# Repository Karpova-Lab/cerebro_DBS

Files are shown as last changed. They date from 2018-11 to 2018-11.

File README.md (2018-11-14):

# CerebroDBS Wireless Deep Brain Stimulation System

This repository contains all files needed to replicate a wireless DBS system that was developed in the [Karpova Lab ](https://www.janelia.org/lab/karpova-lab) at HHMI's Janelia Research Campus.

## Licenses
The MIT License (MIT)

Copyright (c) 2018 Andy Lustig

Permission is hereby granted, free of charge, to any person obtaining a copy of this software and associated documentation files (the “Software”), to deal in the Software without restriction, including without limitation the rights to use, copy, modify, merge, publish, distribute, sublicense, and/or sell copies of the Software, and to permit persons to whom the Software is furnished to do so, subject to the following conditions:

The above copyright notice and this permission notice shall be included in all copies or substantial portions of the Software.

THE SOFTWARE IS PROVIDED “AS IS”, WITHOUT WARRANTY OF ANY KIND, EXPRESS OR IMPLIED, INCLUDING BUT NOT LIMITED TO THE WARRANTIES OF MERCHANTABILITY, FITNESS FOR A PARTICULAR PURPOSE AND NONINFRINGEMENT. IN NO EVENT SHALL THE AUTHORS OR COPYRIGHT HOLDERS BE LIABLE FOR ANY CLAIM, DAMAGES OR OTHER LIABILITY, WHETHER IN AN ACTION OF CONTRACT, TORT OR OTHERWISE, ARISING FROM, OUT OF OR IN CONNECTION WITH THE SOFTWARE OR THE USE OR OTHER DEALINGS IN THE SOFTWARE.

<a rel="license" href="http://creativecommons.org/licenses/by-sa/4.0/">
      </a>
      <br /><span xmlns:dct="http://purl.org/dc/terms/" property="dct:title">Cerebro Wireless Optogenetics System</span> by
      <a xmlns:cc="http://creativecommons.org/ns#" href="https://www.janelia.org/lab/karpova-lab" property="cc:attributionName" rel="cc:attributionURL">
      Andy Lustig </a> is licensed under a  <a rel="license" href="http://creativecommons.org/licenses/by-sa/4.0/">Creative Commons Attribution-ShareAlike 4.0 International License</a>

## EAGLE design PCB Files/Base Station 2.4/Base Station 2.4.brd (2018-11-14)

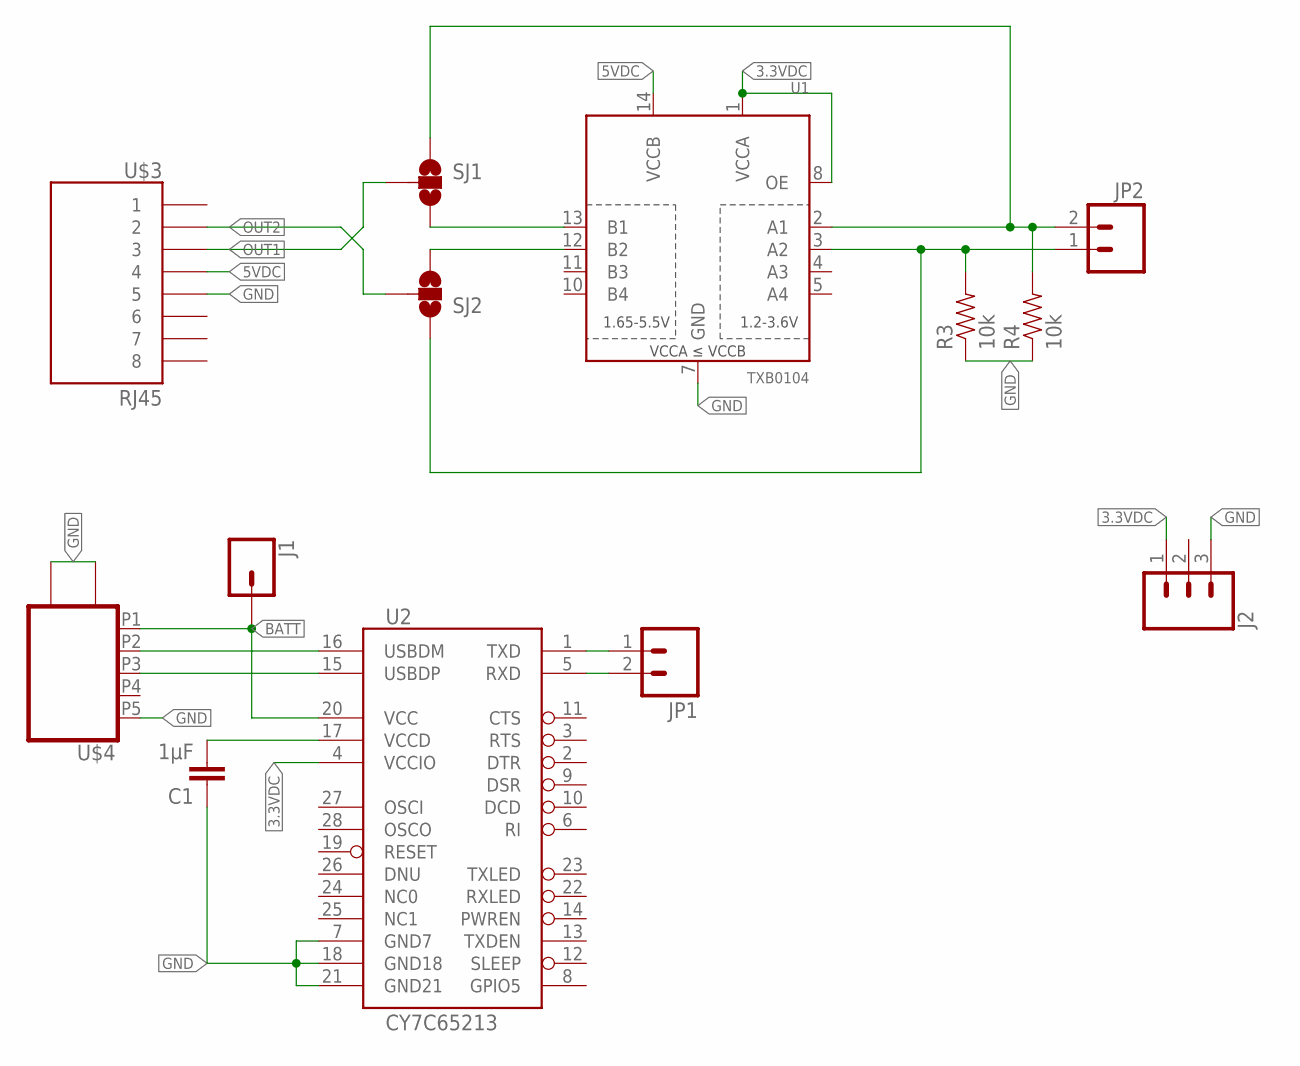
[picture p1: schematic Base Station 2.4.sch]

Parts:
C1: 1µF; 0603
J1: CONN_01PTH_NO_SILK_YES_STOP; 1X01_NO_SILK
J2: CONN_031X03_NO_SILK; 1X03_NO_SILK
JP1, JP2: M021X02_NO_SILK; 1X02_NO_SILK
R3, R4: 10k; 0805
SJ1, SJ2: SOLDERJUMPER_2WAYPASTE2&3; SJ_3_PASTE2&3
U1: TXB0104; TSSOP14
U2: CY7C65213; SSOP28DB
U$3: RJ45; RJ45-8
U$4: USB_MICRO_SOCKET_HORZ_REINFORCED; USB_HORZ_REINFORCED_MICRO

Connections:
3.3VDC: J2.1, U1.1 (VCCA), U1.8 (OE), U2.4 (VCCIO)
5VDC: U1.14 (VCCB), U$3.4
BATT: J1.1, U2.20 (VCC), U$4.P1
GND: C1.1, J2.3, R3.1, R4.1, U1.7 (GND), U2.7 (GND7), U2.18 (GND18), U2.21 (GND21), U$3.5, U$4.G1, U$4.G2, U$4.P5, U$4.P$1, U$4.P$2
unnamed: JP1.1, U2.1 (TXD)
unnamed: JP1.2, U2.5 (RXD)
unnamed: U2.15 (USBDP), U$4.P3
unnamed: U2.16 (USBDM), U$4.P2
unnamed: C1.2, U2.17 (VCCD)
unnamed: JP2.2, R4.2, SJ1.1, U1.2 (A1)
unnamed: JP2.1, R3.2, SJ2.1, U1.3 (A2)
unnamed: SJ2.3, U1.12 (B2)
unnamed: SJ1.3, U1.13 (B1)
NC1: U2.25 (NC1)
OUT1: SJ1.2, U$3.3
OUT2: SJ2.2, U$3.2

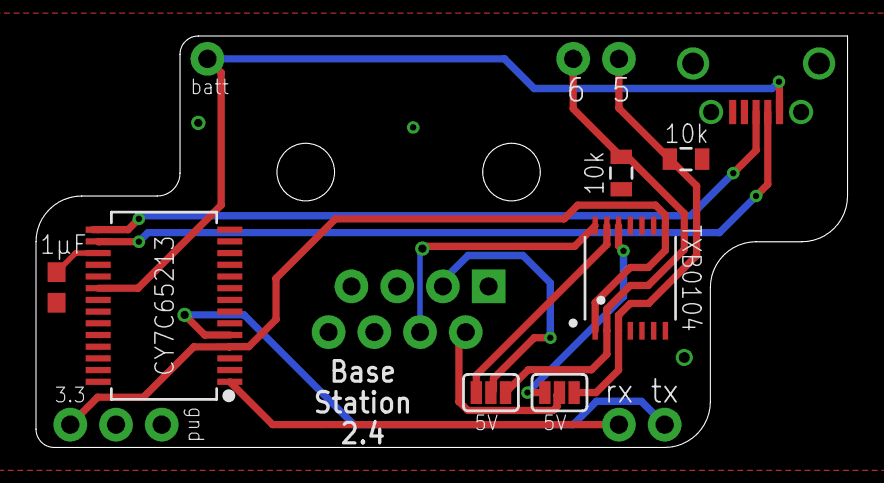
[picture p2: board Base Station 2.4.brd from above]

Board: 2 copper layers, 45.1 x 22.9 mm, 13 parts (0 on the bottom side), 15 nets.

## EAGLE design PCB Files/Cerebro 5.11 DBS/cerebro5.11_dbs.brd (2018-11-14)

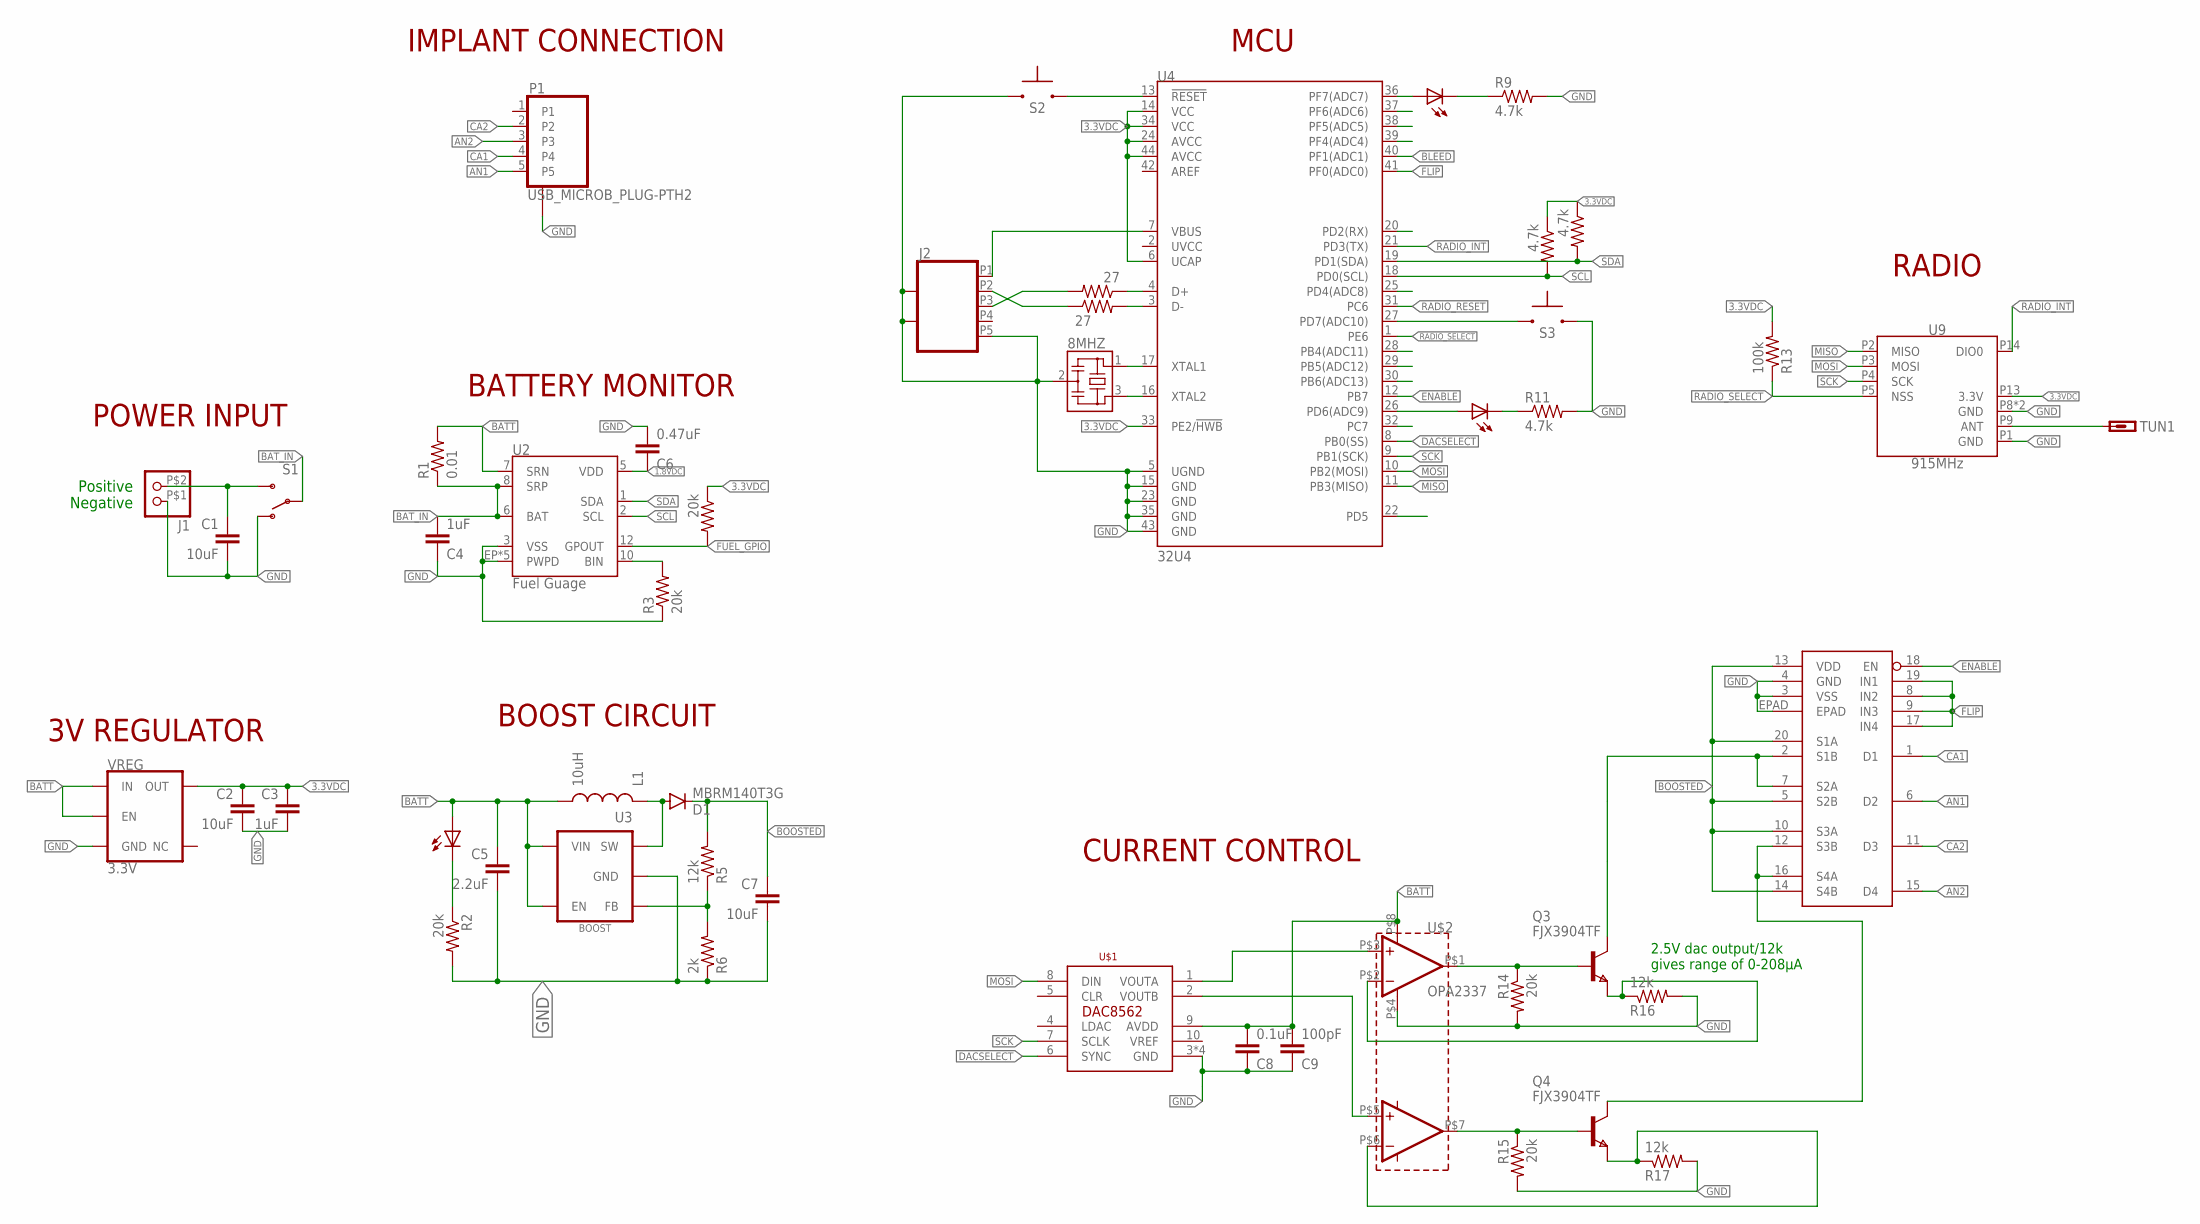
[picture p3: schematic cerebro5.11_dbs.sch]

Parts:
8MHZ: RESONATOR_CSTCE_V; CSTCE_V
C1, C2, C7: 10uF; 0805
C3, C4: 1uF; 0805
C5: 2.2uF; 0805
C6: 0.47uF; 0805
C8: 0.1uF; 0805
C9: 100pF; 0805
D1: MBRM140T3G; POWERMITE
J1: JST_2PINMICRO; MICRO_LOCK_2PIN
J2: USB_MICRO_SOCKET_HORZ_REINFORCED; USB_HORZ_REINFORCED_MICRO
L1: 10uH; 1812
LED1: RED; CHIP-LED0603
LED2, LED3: YLW; CHIP-LED0603
P1: USB_MICROB_PLUG-PTH2; MICRO-B-TH
Q3, Q4: FJX3904TF; SOT323
R1: 0.01; 1206
R2, R3, R4, R14, R15: 20k; 0603-RES
R5: 12k; 0805
R6: 2k; 0603-RES
R7, R8: 27; 0603-RES
R9, R10, R11, R12: 4.7k; 0603-RES
R13: 100k; 0603-RES
R16, R17: 12k; 0603-RES
S1: SWITCH-SPDTREINFORCED_SMD; SWITCH-SPDT-SMD-REINFORCED
S2, S3: SWITCH-MOMENTARY-NO; SWITCH_MOMENTARY_XS
TUN1: ANTENNA; 1X01
U2: Fuel Guage; PDSO-N12
U3: BOOST; SOT23-5
U4: 32U4; QFN-44-NOPAD
U9: 915MHz; RFM69HCW-XXXS2
U$1: DAC8562; WSON-10
U$2: OPA2337; SOT23-8
U$3: ADG1434; LFCSP_5X5
VREG: 3.3V; SOT23-5

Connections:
1.8VDC: C6.1, U2.5 (VDD)
3.3VDC: C2.1, C3.1, R4.1, R10.1, R12.1, R13.2, U4.6 (UCAP), U4.14 (VCC), U4.24 (AVCC), U4.33 (PE2/!HWB), U4.34 (VCC), U4.44 (AVCC), U9.P13 (3.3V), VREG.5 (OUT)
AN1: P1.5, U$3.6 (D2)
AN2: P1.3, U$3.15 (D4)
BATT: C5.1, C8.2, C9.2, L1.P$2 (2), L1.P$4 (2), LED1.A, R1.2, U2.7 (SRN), U3.4 (EN), U3.5 (VIN), U$1.9 (AVDD), U$2.P$8 (V+), VREG.1 (IN), VREG.3 (EN)
BAT_IN: C4.2, R1.1, S1.2, U2.6 (BAT), U2.8 (SRP)
BLEED: U4.40 (PF1(ADC1))
BOOSTED: C7.1, D1.CATHODE (C), R5.2, U$3.5 (S2B), U$3.10 (S3A), U$3.13 (VDD), U$3.14 (S4B), U$3.20 (S1A)
CA1: P1.4, U$3.1 (D1)
CA2: P1.2, U$3.11 (D3)
DACSELECT: U4.8 (PB0(SS)), U$1.6 (SYNC)
ENABLE: U4.12 (PB7), U$3.18 (EN)
FLIP: U4.41 (PF0(ADC0)), U$3.8 (IN2), U$3.9 (IN3), U$3.17 (IN4), U$3.19 (IN1)
FUEL_GPIO: R4.2, U2.12 (GPOUT)
GND: 8MHZ.2, C1.2, C2.2, C3.2, C4.1, C5.2, C6.2, C7.2, C8.1, C9.1, J1.P$1 (1), J2.G1, J2.G2, J2.P5, J2.P$1, J2.P$2, P1.P$1 (GND_PINS), P1.P$2 (GND_PINS), R2.2, R3.1, R6.1, R9.2, R11.2, R14.2, R15.2, R16.2, R17.2, S1.1 (O), S2.P$1 (1), S3.P$2 (2), U2.3 (VSS), U2.EP (PWPD), U2.EP1 (PWPD), U2.EP2 (PWPD), U2.EP3 (PWPD), U2.EP4 (PWPD), U3.2 (GND), U4.5 (UGND), U4.15 (GND), U4.23 (GND), U4.35 (GND), U4.43 (GND), U9.P1 (GND), U9.P8 (GND), U9.P10 (GND), U$1.3 (GND), U$1.G1 (GND), U$1.G2 (GND), U$1.G3 (GND), U$2.P$4 (V-), U$3.3 (VSS), U$3.4 (GND), U$3.EPAD, VREG.2 (GND)
MISO: U4.11 (PB3(MISO)), U9.P2 (MISO)
MOSI: U4.10 (PB2(MOSI)), U9.P3 (MOSI), U$1.8 (DIN)
unnamed: Q3.2 (B), R14.1, U$2.P$1 (OUTA)
unnamed: Q4.2 (B), R15.1, U$2.P$7 (OUTB)
unnamed: Q4.3 (E), R17.1, U$2.P$6 (INB-)
unnamed: C1.1, J1.P$2 (2), S1.3 (S)
unnamed: Q3.3 (E), R16.1, U$2.P$2 (INA-)
unnamed: LED1.C, R2.1
unnamed: R5.1, R6.2, U3.3 (FB)
unnamed: 8MHZ.1, U4.17 (XTAL1)
unnamed: 8MHZ.3, U4.16 (XTAL2)
unnamed: J2.P1, U4.7 (VBUS)
unnamed: D1.ANODE (A), L1.P$1 (1), L1.P$3 (1), U3.1 (SW)
unnamed: R7.1, U4.4 (D+)
unnamed: R8.2, U4.3 (D-)
unnamed: J2.P3, R7.2
unnamed: J2.P2, R8.1
unnamed: LED3.C, R11.1
unnamed: S3.P$1 (1), U4.27 (PD7(ADC10))
unnamed: TUN1.1, U9.P9 (ANT)
unnamed: LED2.C, R9.1
unnamed: LED2.A, U4.36 (PF7(ADC7))
unnamed: R3.2, U2.10 (BIN)
unnamed: Q4.1 (C), U$3.12 (S3B), U$3.16 (S4A)
unnamed: LED3.A, U4.26 (PD6(ADC9))
unnamed: U$1.1 (VOUTA), U$2.P$3 (INA+)
unnamed: U$1.2 (VOUTB), U$2.P$5 (INB+)
unnamed: Q3.1 (C), U$3.2 (S1B), U$3.7 (S2A)
RADIO_INT: U4.21 (PD3(TX)), U9.P14 (DIO0)
RADIO_RESET: U4.31 (PC6)
RADIO_SELECT: R13.1, U4.1 (PE6), U9.P5 (NSS)
RESET: S2.P$2 (2), U4.13 (!RESET)
SCK: U4.9 (PB1(SCK)), U9.P4 (SCK), U$1.7 (SCLK)
SCL: R10.2, U2.2 (SCL), U4.18 (PD0(SCL))
SDA: R12.2, U2.1 (SDA), U4.19 (PD1(SDA))

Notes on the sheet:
Positive
Negative
BOOST CIRCUIT
CURRENT CONTROL
RADIO
3V REGULATOR
BATTERY MONITOR
POWER INPUT
IMPLANT CONNECTION
MCU
2.5V dac output/12k gives range of 0-208µA

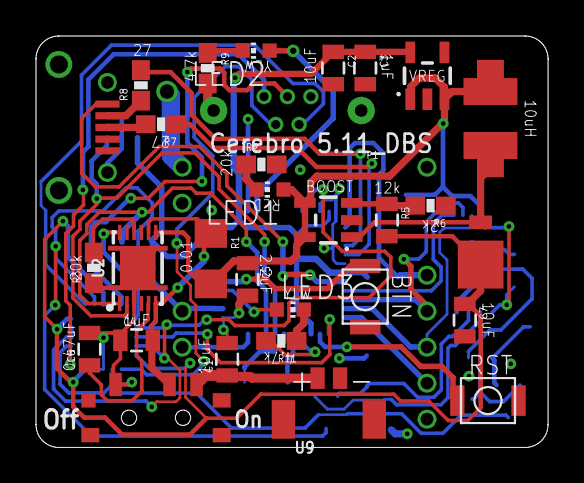
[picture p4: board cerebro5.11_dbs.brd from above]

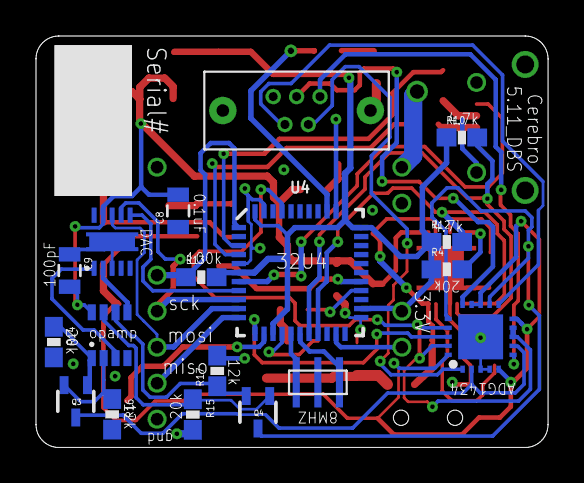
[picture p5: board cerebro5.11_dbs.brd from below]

Board: 2 copper layers, 28.4 x 22.9 mm, 49 parts (18 on the bottom side), 48 nets.

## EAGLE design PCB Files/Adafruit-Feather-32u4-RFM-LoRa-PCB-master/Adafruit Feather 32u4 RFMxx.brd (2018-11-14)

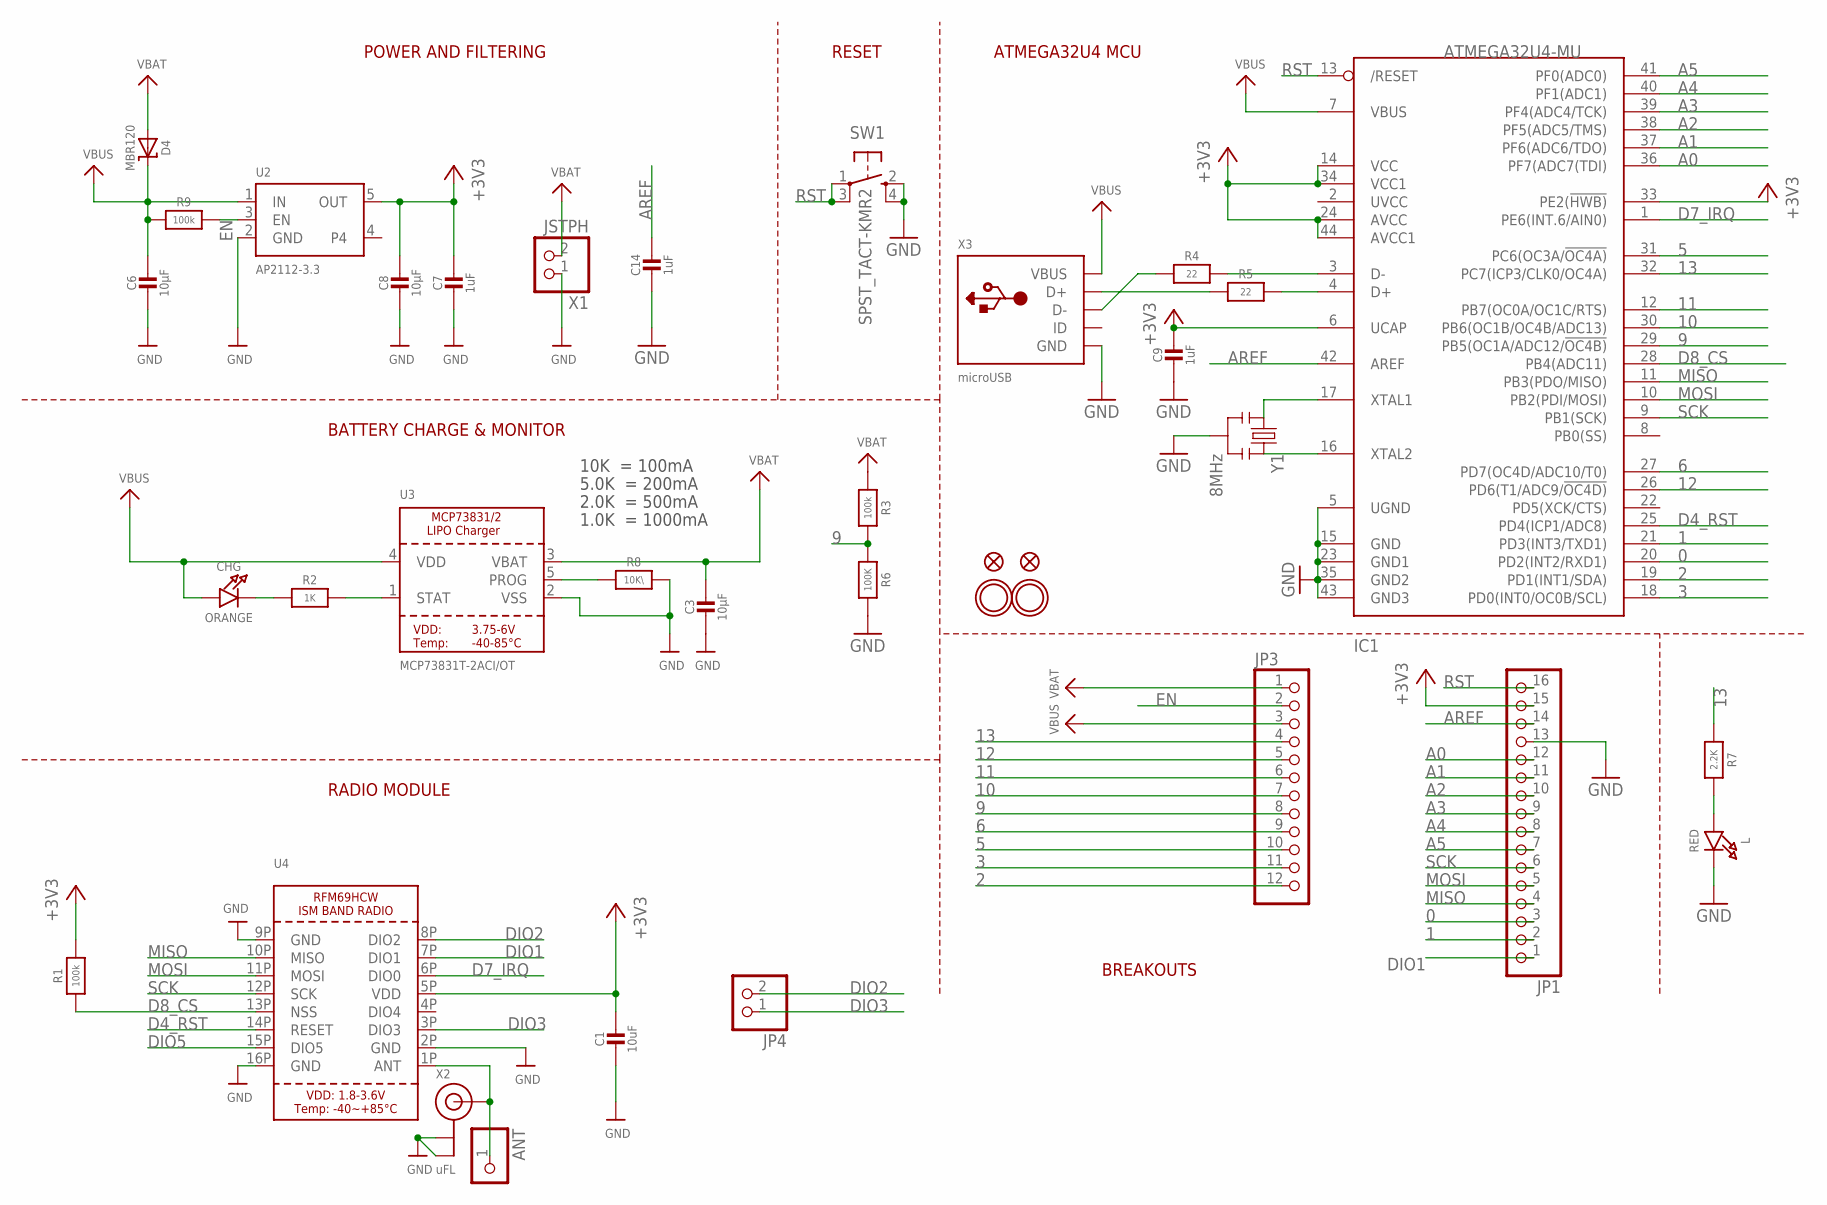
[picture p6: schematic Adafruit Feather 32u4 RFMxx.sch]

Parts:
ANT: HEADER-1X1ROUND; 1X01_ROUND
C1: 10uF; 0805-NO
C3, C6, C8: 10µF; 0805-NO
C7, C14: 1uF; 0603-NO
C9: 1uF; _0603MP
CHG: ORANGE; CHIPLED_0805_NOOUTLINE
D4: MBR120; SOD-123
IC1: ATMEGA32U4-MU; TQFN44_7MM
JP1: HEADER-1X16ROUND; 1X16_ROUND
JP3: HEADER-1X12; 1X12_ROUND
JP4: HEADER-1X2ROUND; 1X02_ROUND
L: RED; CHIPLED_0805_NOOUTLINE
R1, R3, R9: 100k; 0603-NO
R2: 1K; 0603-NO
R4, R5: 22; 0603-NO
R6: 100K; 0603-NO
R7: 2.2K; 0603-NO
R8: 10K\; 0603-NO
SW1: SPST_TACT-KMR2; KMR2
U2: AP2112-3.3; SOT23-5
U3: MCP73831T-2ACI/OT; SOT23-5
U4: RFM69HCW_SMT; RFMHCW_SMT
U$31, U$32: MOUNTINGHOLE2.5; MOUNTINGHOLE_2.5_PLATED
U$34, U$35: FIDUCIAL""; FIDUCIAL_1MM
X1: JSTPH; JSTPH2
X2: uFL; U.FL
X3: microUSB; 4UCONN_20329_V2
Y1: 8MHz; RESONATOR-SMD

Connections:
0: IC1.20 (PD2(INT2/RXD1)), JP1.3
1: IC1.21 (PD3(INT3/TXD1)), JP1.2
2: IC1.19 (PD1(INT1/SDA)), JP3.12
3: IC1.18 (PD0(INT0/OC0B/SCL)), JP3.11
5: IC1.31 (PC6(OC3A/!OC4A)), JP3.10
6: IC1.27 (PD7(OC4D/ADC10/T0)), JP3.9
9: IC1.29 (PB5(OC1A/ADC12/!OC4B)), JP3.8, R3.2, R6.1
10: IC1.30 (PB6(OC1B/OC4B/ADC13)), JP3.7
11: IC1.12 (PB7(OC0A/OC1C/RTS)), JP3.6
12: IC1.26 (PD6(T1/ADC9/!OC4D)), JP3.5
13: IC1.32 (PC7(ICP3/CLK0/OC4A)), JP3.4, R7.1
+3V3: C1.1, C7.1, C8.1, C9.1, IC1.6 (UCAP), IC1.14 (VCC), IC1.24 (AVCC), IC1.33 (PE2(!HWB)), IC1.34 (VCC1), IC1.44 (AVCC1), JP1.15, R1.2, U2.5 (OUT), U4.5P (VDD)
A0: IC1.36 (PF7(ADC7(TDI)), JP1.12
A1: IC1.37 (PF6(ADC6/TDO)), JP1.11
A2: IC1.38 (PF5(ADC5/TMS)), JP1.10
A3: IC1.39 (PF4(ADC4/TCK)), JP1.9
A4: IC1.40 (PF1(ADC1)), JP1.8
A5: IC1.41 (PF0(ADC0)), JP1.7
ANT: ANT.1, U4.1P (ANT), X2.3 (SIGNAL)
AREF: C14.1, IC1.42 (AREF), JP1.14
D4_RST: IC1.25 (PD4(ICP1/ADC8)), U4.14P (RESET)
D7_IRQ: IC1.1 (PE6(INT.6/AIN0)), U4.6P (DIO0)
D8_CS: IC1.28 (PB4(ADC11)), R1.1, U4.13P (NSS)
D+: IC1.4 (D+), R5.2
D-: IC1.3 (D-), R4.2
DIO1: JP1.1, U4.7P (DIO1)
DIO2: JP4.2, U4.8P (DIO2)
DIO3: JP4.1, U4.3P (DIO3)
DIO5: U4.15P (DIO5)
EN: JP3.2, R9.2, U2.3 (EN)
GND: C1.2, C3.2, C6.2, C7.2, C8.2, C9.2, C14.2, IC1.5 (UGND), IC1.15 (GND), IC1.23 (GND1), IC1.35 (GND2), IC1.43 (GND3), JP1.13, L.C, R6.2, R8.2, SW1.2 (S), SW1.4 (S1), U2.2 (GND), U3.2 (VSS), U4.2P (GND), U4.9P (GND), U4.16P (GND), X1.1, X2.1 (GND), X2.2 (GND), X3.BASE@1 (GND), X3.BASE@2 (GND), X3.GND, X3.SPRT@1 (GND), X3.SPRT@2 (GND), X3.SPRT@3 (GND), X3.SPRT@4 (GND), Y1.2
MISO: IC1.11 (PB3(PDO/MISO)), JP1.4, U4.10P (MISO)
MOSI: IC1.10 (PB2(PDI/MOSI)), JP1.5, U4.11P (MOSI)
unnamed: CHG.C, R2.1
unnamed: L.A, R7.2
unnamed: R2.2, U3.1 (STAT)
unnamed: R8.1, U3.5 (PROG)
unnamed: IC1.16 (XTAL2), Y1.3
unnamed: IC1.17 (XTAL1), Y1.1
unnamed: R5.1, X3.D+
unnamed: R4.1, X3.D-
RST: IC1.13 (/RESET), JP1.16, SW1.1, SW1.3 (P1)
SCK: IC1.9 (PB1(SCK)), JP1.6, U4.12P (SCK)
VBAT: C3.1, D4.A, JP3.1, R3.1, U3.3 (VBAT), X1.2
VBUS: C6.1, CHG.A, D4.C, IC1.7 (VBUS), JP3.3, R9.1, U2.1 (IN), U3.4 (VDD), X3.VBUS

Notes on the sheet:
POWER AND FILTERING
RESET
ATMEGA32U4 MCU
10K = 100mA
5.0K = 200mA
2.0K = 500mA
1.0K = 1000mA
BATTERY CHARGE & MONITOR
BREAKOUTS
RADIO MODULE

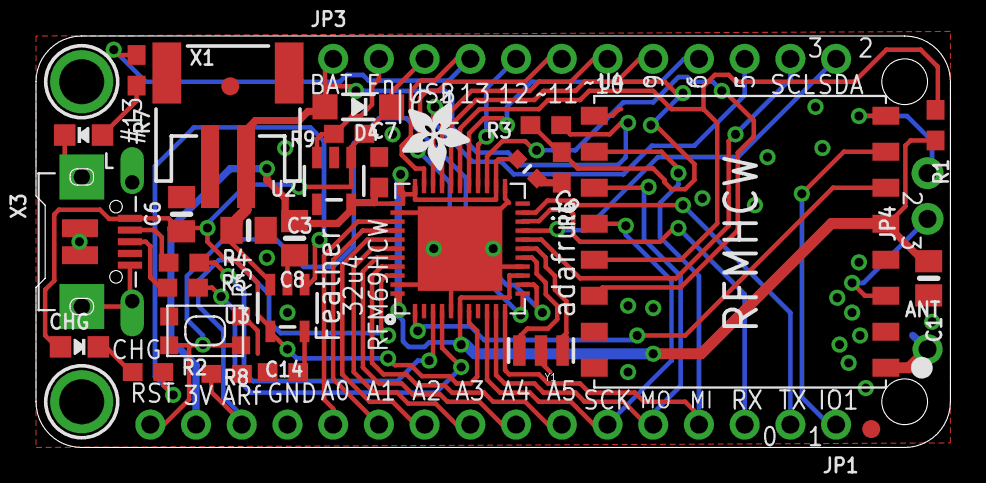
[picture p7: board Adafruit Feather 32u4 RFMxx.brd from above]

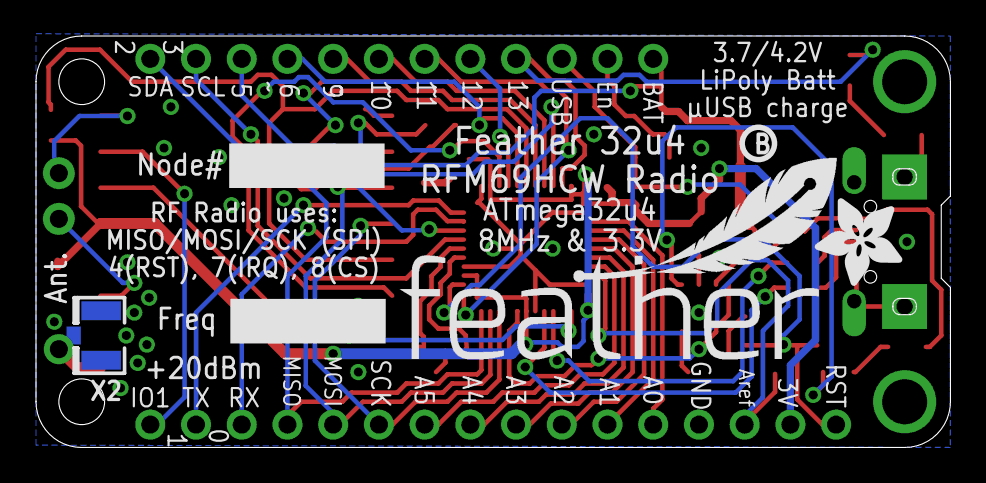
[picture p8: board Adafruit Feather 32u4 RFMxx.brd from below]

Board: 2 copper layers, 50.8 x 22.9 mm, 40 parts (4 on the bottom side), 44 nets.

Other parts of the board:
U$4: ADAFRUIT_5MM
U$5: FEATHERLOGO
U$6: PCBFEAT-REV-040
U$7: ADAFRUIT_3.5MM

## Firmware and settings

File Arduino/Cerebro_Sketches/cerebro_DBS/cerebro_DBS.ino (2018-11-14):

/*~~~~~~~~~~~~~~~~~~~~~~~~~~~~~~~~~~~~~~~~~~~~~~~~~~~~~~~~~~~~~~~~~~~~~~~~~~~~~~
MIT License

Copyright (c) 2018 Andy S. Lustig

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
THE SOFTWARE IS PROVIDED "AS IS", WITHOUT WARRANTY OF ANY KIND, EXPRESS OR
IMPLIED, INCLUDING BUT NOT LIMITED TO THE WARRANTIES OF MERCHANTABILITY,
FITNESS FOR A PARTICULAR PURPOSE AND NONINFRINGEMENT. IN NO EVENT SHALL THE
AUTHORS OR COPYRIGHT HOLDERS BE LIABLE FOR ANY CLAIM, DAMAGES OR OTHER
LIABILITY, WHETHER IN AN ACTION OF CONTRACT, TORT OR OTHERWISE, ARISING FROM,
OUT OF OR IN CONNECTION WITH THE SOFTWARE OR THE USE OR OTHER DEALINGS IN THE
SOFTWARE.
~~~~~~~~~~~~~~~~~~~~~~~~~~~~~~~~~~~~~~~~~~~~~~~~~~~~~~~~~~~~~~~~~~~~~~~~~~~~~~~*/
const uint8_t VERSION = 0; // 2018-11-14

#include <EEPROM.h>
#include <Electrode.h>
#include <SparkFunBQ27441.h>      //https://github.com/sparkfun/SparkFun_BQ27441_Arduino_Library
#include <Radio.h>                //https://github.com/LowPowerLab/RFM69
#include <avr/wdt.h>
#include <util/delay.h>

#define SERIAL_NUMBER_ADDRESS 0
#define WAVEFORM_ADDRESS 1
#define MISSING_ARRAY_ADDRESS 17

WaveformData waveform;
IntegerPayload integerMessage;  
Info cerebroInfo;

uint16_t meterVal = 0;

const uint8_t amberLED = A0; //32u4 pin 36
const uint8_t greenLED = 12; //32u4 pin 26
const uint8_t userBTN = 6; //32u4 pin 27
Electrode stim(&DDRB, &PORTB, 0,  //DAC SYNC pin is the chip select pin. p8/PB0/D17.
               &DDRB, &PORTB, 7,  //Switch enable pin. p12/PB7/D11
               &DDRF, &PORTF, 0); //Switch flip pin. p41/PF0/A5

uint8_t channel;
Radio radio(7,1); //slave select pin, interrupt pin
uint16_t msgCount = 0;
uint16_t missedCount = 0;
uint16_t trigCount = 0;
uint8_t batteryUpdateFrequency = 10;
bool reportBatteryFlag = false;

void setup() {
  SPI.begin();
  stim.begin();
  Serial.begin(115200);

  // Initialize waveform
  EEPROM.get(WAVEFORM_ADDRESS,waveform);

  // UI setup
  pinMode(userBTN,INPUT_PULLUP);
  pinMode(greenLED,OUTPUT);
  pinMode(amberLED,OUTPUT);
  digitalWrite(amberLED,HIGH);

  //*** Battery Monitor ***//
  if (!lipo.begin()){
	// If communication fails, print an error message and loop forever.
    Serial.println("Error: Unable to communicate with BQ27441.");
    while(1){ //blink error
      digitalWrite(amberLED,HIGH);
      delay(200);
      digitalWrite(amberLED,LOW);
      delay(200);
    }
  }
  Serial.println("Connected to BQ27441!");
  lipo.setCapacity(400);
  while(lipo.soc()==0){
    delay(1);
    //wait;
  }

  //*** Radio ***//
  EEPROM.get(SERIAL_NUMBER_ADDRESS,channel); // we use our unique serial number as our radio communication channel
  radio.radioSetup(CEREBRO,true,channel); //nodeID, autopower on;
  integerMessage.variable = 'Y';
  integerMessage.value = millis();
  if (radio.sendWithRetry(BASESTATION, (const void*)(&integerMessage), sizeof(integerMessage),3,250)){
    Serial.println("Connected to Base Station");
  }
  else{
    Serial.println("Failed to Connect to Base Station"); 
    //turn on green LED?
  }
  printChannel();
  reportVersion();
  digitalWrite(amberLED,LOW);
}

void loop() {
  //
  if (!digitalRead(userBTN)){ //user button is pushed
    uint16_t holdCount = 0;
    uint16_t holdThresh = 5000; //need to hold the button for 5 seconds
    digitalWrite(greenLED,HIGH);
    while(!digitalRead(userBTN) && holdCount < holdThresh){
      delay(1);
      holdCount++;
    }
    if (holdCount >= holdThresh) { //Button was held down for 5 seconds
      //Reset settings that are in memory
      EEPROM.update(SERIAL_NUMBER_ADDRESS, 0);
      waveform = {0,0,150,60,150,60,125,60000};
      EEPROM.put(WAVEFORM_ADDRESS,waveform);  //save new waveform to memory

      //blink to indicate button was held long enough and reset has occured
      uint8_t blinkDelay = 85;
      digitalWrite(greenLED,LOW);
      delay(blinkDelay);
      digitalWrite(greenLED,HIGH);
      delay(blinkDelay);
      digitalWrite(greenLED,LOW);
      delay(blinkDelay);
      digitalWrite(greenLED,HIGH);
      delay(blinkDelay);

      //restart MCU so it will 
      Serial.println("Restarting...");
      wdt_enable(WDTO_15MS);  // turn on the WatchDog timer
      while(1){}              // do nothing and wait for the reset
    }
    else{
      digitalWrite(greenLED,LOW);
    }
  }
  if (Serial.available()){
    char msg = Serial.read();
    if (msg=='?'){
      printChannel();
      Serial.print("Version: ");
      Serial.println(VERSION);

    }
  }
  //check for any received packets
  if (radio.receiveDone()){
    uint8_t dlay = 80;
    if (radio.DATALEN==1){ //received a command or a request for data
      sendACK();
      switch (radio.DATA[0]){
        case 'o':
          stim.positive();break;
        case 'n':
          stim.negative();break;
        case 'B':
          reportBattery();break;
        case 'N':
          msgCount = 0;
          missedCount = 0;
          reportVersion();
          delay(dlay);
          reportWaveform();
          delay(dlay);
          reportBattery();break;
        case '+':
          testStim(waveform.posAmp);break;
        case '0':
          stim.off();break;
        default:
          Serial.print("received '");Serial.print(radio.DATA[0]);
          Serial.println("'. Command not recognized");break;
      }
    }
    else if (radio.DATALEN == sizeof(waveform)){ //received a waveform data
      sendACK();
      msgCount++;
      waveform = *(WaveformData*)radio.DATA;  //update waveform
      EEPROM.put(WAVEFORM_ADDRESS,waveform);  //save new waveform to memory
      reportWaveform();
    }
    else if (radio.DATALEN == sizeof(integerMessage)){ //received a variable update
      sendACK();
      integerMessage = *(IntegerPayload*)radio.DATA;
      switch (integerMessage.variable){
        case 'T':
          trigCount++;
          checkForMiss();
          testStim(waveform.posAmp);
          stimulate(waveform.startDelay,
                    waveform.posAmp, waveform.posDur,
                    waveform.negAmp, waveform.negDur, 
                    waveform.freq, 
                    waveform.trainDur);
          break;
        case 'S': // Receiving a new Cerebro S/N
          EEPROM.update(SERIAL_NUMBER_ADDRESS, integerMessage.value);
          reportVersion();
          Serial.print("New Serial:");
          Serial.println(integerMessage.value);
          Serial.println("Restarting...");
          wdt_enable(WDTO_15MS);  // turn on the WatchDog timer
          while(1){}              // do nothing and wait for the reset
          break;
        case 'M':
          checkForMiss();
          printMissed();
          break;
      }
    }
    else{
      Serial.println("Unexpected Data size received");
    }
  }
}

void sendACK(){
  if (radio.ACKRequested()){
    radio.sendACK();
  }
}
 
void checkForMiss(){
  msgCount++;
  if (trigCount%batteryUpdateFrequency==0){
    reportBatteryFlag = true;
  }
  if (msgCount!=integerMessage.value){
    for (msgCount; msgCount<integerMessage.value; msgCount++){
      EEPROM.put(MISSING_ARRAY_ADDRESS + 2*missedCount,msgCount);
      missedCount++;
    }
  }
}

void printMissed(){
  reportBattery();
  delay(200);
  uint16_t missed;
  // Serial.print("missed,");Serial.println(missedCount);
  integerMessage.variable = 'M';
  integerMessage.value = missedCount;
  if (radio.sendWithRetry(BASESTATION, (const void*)(&integerMessage), sizeof(integerMessage),3,250)){
    // Serial.print("Sent");Serial.println(missedCount);
  }
  else{
    // Serial.println("Sending again");
  }
  integerMessage.variable = 'm';
  for (int i = 0; i <missedCount; i++ ){
    EEPROM.get(MISSING_ARRAY_ADDRESS+2*i,missed);
    integerMessage.value = (int)missed;
    if (radio.sendWithRetry(BASESTATION, (const void*)(&integerMessage), sizeof(integerMessage),3,250)){
      // Serial.println(missed);
    }
    else{
      // Serial.println("Sending again");
    }
  }
  // Serial.println("done");
}

void reportVersion(){
  EEPROM.get(SERIAL_NUMBER_ADDRESS,cerebroInfo.serialNumber);
  cerebroInfo.firmware = VERSION;
  cerebroInfo.msgCount = msgCount;
  if (radio.sendWithRetry(BASESTATION, (const void*)(&cerebroInfo), sizeof(cerebroInfo),4,20)){
    // Serial.println("Version sent successfully");
  }
  else{
    // Serial.println("Error sending Version");
  }
}

void reportWaveform(){
  waveform.msgCount = msgCount;
  if (radio.sendWithRetry(BASESTATION, (const void*)(&waveform), sizeof(waveform),4,20)){
    // Serial.println("Waveform sent successfully");
  }
  else{
    // Serial.println("Error sending Waveform");
  }
}

void reportBattery(){
  integerMessage.variable = 'B';
  integerMessage.value = lipo.soc();
  integerMessage.msgCount = msgCount;
  if (radio.sendWithRetry(BASESTATION, (const void*)(&integerMessage), sizeof(integerMessage),2,20)){
    //
  }
  else{
    // Serial.println("Battery info send fail");
  }
}

void printChannel(){
  Serial.print("Channel: ");
  Serial.println(channel);
}

void stimulate(uint16_t startDelay, uint16_t posAmplitude, uint16_t posDuration, uint16_t negAmplitude, uint16_t negDuration, uint16_t freq, uint16_t trainDur )
{
  const uint8_t set_and_switch_delay = 28;
  posAmplitude = int(posAmplitude*19.69) << 4; //current output range is 0-208µA, DAC resolution is 12bit. 2^12/208 = 19.69. Shift to the left becauase the we're using 12bit DAC as opposed to 16bit
  negAmplitude = int(negAmplitude*19.69) << 4; 

  stim.setValue(posAmplitude << 4);
  float interDelay = 1000000.0 / freq - (posDuration+negDuration+set_and_switch_delay);
  Serial.println(interDelay);
  delay(startDelay);
  uint32_t clockStart = millis();
  while ((millis() - clockStart) < trainDur)
  {
    
    stim.setValue(posAmplitude);
    stim.positive();
    stim.on();
    delayMicroseconds(posDuration - set_and_switch_delay);
    stim.setValue(negAmplitude);
    stim.negative();
    delayMicroseconds(negDuration);
    stim.off();
    delayMicroseconds(interDelay);
  }
}

void testStim(uint16_t amplitude)
{
  stim.on();
  Serial.print(millis());
  if (!stim.isPositive)
  {
    Serial.print(" (Positive) ");
    stim.positive();
  }
  else
  {
    Serial.print(" (Negative) ");
    stim.negative();
  }
  Serial.println(amplitude);
  amplitude *= 19.69;
  stim.setValue(amplitude << 4);
}

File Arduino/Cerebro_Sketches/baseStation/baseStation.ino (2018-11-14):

/*~~~~~~~~~~~~~~~~~~~~~~~~~~~~~~~~~~~~~~~~~~~~~~~~~~~~~~~~~~~~~~~~~~~~~~~~~~~~~~
MIT License

Copyright (c) 2015-2018 Andy S. Lustig

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
THE SOFTWARE IS PROVIDED "AS IS", WITHOUT WARRANTY OF ANY KIND, EXPRESS OR
IMPLIED, INCLUDING BUT NOT LIMITED TO THE WARRANTIES OF MERCHANTABILITY,
FITNESS FOR A PARTICULAR PURPOSE AND NONINFRINGEMENT. IN NO EVENT SHALL THE
AUTHORS OR COPYRIGHT HOLDERS BE LIABLE FOR ANY CLAIM, DAMAGES OR OTHER
LIABILITY, WHETHER IN AN ACTION OF CONTRACT, TORT OR OTHERWISE, ARISING FROM,
OUT OF OR IN CONNECTION WITH THE SOFTWARE OR THE USE OR OTHER DEALINGS IN THE
SOFTWARE.
~~~~~~~~~~~~~~~~~~~~~~~~~~~~~~~~~~~~~~~~~~~~~~~~~~~~~~~~~~~~~~~~~~~~~~~~~~~~~~~*/

//Documentation for this project can be found at https://karpova-lab.github.io/cerebro/

#include <Radio.h>  //https://github.com/LowPowerLab/RFM69
#include <SPI.h>
#include <EEPROM.h>
#include <avr/wdt.h>

#define CHANNEL_ADDRESS 0

const uint8_t VERSION = 0; //2018-11-14

const uint8_t LED = 13;
const uint8_t TRIGGER_PIN = 6;
const uint8_t STOP_PIN = 5;

uint8_t netID;

Radio radio(8,7); //slave select pin, interrupt pin
WaveformData newWaveform;
WaveformData currentWaveform;
IntegerPayload integerMessage;
Info cerebroInfo;

uint32_t  valsFromParse[7];
uint32_t  startTime = 0;
uint32_t  spamFilter = 0;
uint32_t  triggerClock = 0;
uint16_t  msgCount = 0;
bool      ignoreFilter = false;
bool      warningsOn = true;

void setup() {
  Serial1.begin(57600);
  delay(10);
  pinMode(LED, OUTPUT);

  EEPROM.get(CHANNEL_ADDRESS,netID);
  radio.radioSetup(1,false,netID); //nodeID, autopower off;
  pinMode(TRIGGER_PIN,INPUT);
  pinMode(STOP_PIN,INPUT);
  startTime = millis();
  newSession();
}

void loop() {
  ////////////Receive Message From Bcontrol
  if (digitalRead(TRIGGER_PIN)) {
    while(digitalRead(TRIGGER_PIN)){
      //wait until signal goes low
    }
    triggerCommandReceived();
  }
  //if we read a high signal on pin 6, send a stop command to cerebro
  if (digitalRead(STOP_PIN)) {
    while(digitalRead(STOP_PIN)){
      //wait until signal goes low
    }
    stopCommandReceived();
  }

  ///////////Receive Message From Xavier//////////////////
  if (Serial1.available()){
    char msg = Serial1.read();
    if (msg=='W'){  //parse data then send new waveform
      parseData();
      sendWaveformUpdate();
    }
    else if (msg=='S' || msg == 'L' || msg == 'R' ||  msg == 'l' ||  msg == 'r'){ //parse data then send radio message with integer
      parseData();
      delay(500);
      sendMsgAndVal(msg,valsFromParse[0]);
    }
    else if (msg=='T'){
      triggerCommandReceived();
    }
    else if (msg=='A'){
      stopCommandReceived();
    }
    else if(msg=='M'){
      requestMissed();
    }
    else if(msg=='N'){
      newSession();
    }
    else if (msg=='K'){
      parseData();
      uint8_t newNetworkID = valsFromParse[0];
      Serial1.print("\nChanging to channel:");
      Serial1.println(newNetworkID);
      EEPROM.update(CHANNEL_ADDRESS, newNetworkID);
      Serial1.println("Restarting...");
      wdt_enable(WDTO_15MS);  // turn on the WatchDog timer
      while(1){}              // do nothing and wait for the reset
    }
    else if(msg=='?'){
      Serial1.print("Channel: ");
      Serial1.println(netID);
      Serial1.print("Base Version,");Serial1.print(VERSION);newline();
    }
    else if (msg!='\n'){
      relayMsg(msg);
    }
  }

  ///////////Receive Message From Cerebro///////
  if (radio.receiveDone()){
    switch (radio.DATALEN) {
      case sizeof(cerebroInfo):
        if (radio.ACKRequested()){
          radio.sendACK();
        }
        cerebroInfo = *(Info*)radio.DATA;
        printCerebroInfo();
        break;
      case sizeof(currentWaveform):
        if (radio.ACKRequested()){
          radio.sendACK();
        }
        currentWaveform = *(WaveformData*)radio.DATA;
        spamFilter = currentWaveform.startDelay + currentWaveform.trainDur;
        warningsOn = false;
        printWaveform(currentWaveform,true);
        break;
      case  sizeof(integerMessage):
        if (radio.ACKRequested()){
          radio.sendACK();
        }
        integerMessage = *(IntegerPayload*)radio.DATA;
        if(integerMessage.variable == 'B'){
          printBattery(integerMessage.msgCount,integerMessage.value);
        }
        else if (integerMessage.variable == 'M'){
          Serial1.print("Total Missed,");Serial1.print(integerMessage.value);newline();
        }
        else if (integerMessage.variable =='m'){
          Serial1.print("Missed Message Index,");Serial1.print(integerMessage.value);newline();
        }
        else if (integerMessage.variable == 'Y'){
          Serial1.print("Cerebro turned on and connected,");Serial1.print(integerMessage.value);//print time it took to startup and send connection message.
        }
        break;
    }
  }
}

void parseData(){
  char msgData[30] = "";
  Serial1.readBytesUntil('\n',msgData,30);
  char* msgPointer;
  msgPointer = strtok(msgData,",");
  char i = 0;
  while (msgPointer!=NULL){
    valsFromParse[i] = atol(msgPointer);
    msgPointer = strtok(NULL,",");
    i++;
  }
}

void sendMsgAndVal(char msg,unsigned int val){
  integerMessage.variable = msg;
  integerMessage.value = val;
  Serial1.print("\nSending '"); Serial1.print(msg);Serial1.print("' ") ;Serial1.print(integerMessage.value);Serial1.print("...");
  if (radio.sendWithRetry(CEREBRO, (const void*)(&integerMessage), sizeof(integerMessage),5)){
    Serial1.print("data received");newline();
  }
  else{
    Serial1.print("*X&data send fail");newline();
  }
}

void newSession(){
  startTime = millis();
  msgCount = 0;
  Serial1.print("\n*BaseOn&Base Version,");Serial1.print(VERSION);newline();
  uint32_t theVals[1] = {netID};
  sendDataToXavier("Base Channel",theVals,1);
  Serial1.print("Base Channel,");Serial1.print(netID);newline();

  char msg = 'N';
  if (radio.sendWithRetry(CEREBRO, &msg, 1, 3)){
    // Serial1.print("Connected!");
  }
  else{
    Serial1.print("*X&Error communicating with Cerebro\n\n");
  }
}

void relayMsg(char msg){
  if (radio.sendWithRetry(CEREBRO, &msg, 1, 0)){  // 0 = only 1 attempt, no retries
  }
  else{
    Serial1.print("*X&");
    printTime();Serial1.print("Tried Sending ''");Serial1.print(msg);
    Serial1.print("'', ACK not received");newline();
  }
}

void printCerebroInfo(){
  uint32_t theVals[2] = {cerebroInfo.firmware, cerebroInfo.serialNumber};
  sendDataToXavier("Cerebro Info",theVals,2);
  Serial1.print("Cerebro Version,");Serial1.print(cerebroInfo.firmware);newline();
  Serial1.print("Serial Number,");Serial1.print(cerebroInfo.serialNumber);newline();
}


void printBattery(uint16_t batteryMsgCount, uint8_t batteryStatus){
  printTime();
  Serial1.print("[");Serial1.print(batteryMsgCount);Serial1.print("]");
  uint32_t theVals[] = {batteryStatus};
  uint8_t numElements = sizeof(theVals)/sizeof(uint32_t);
  sendDataToXavier("Battery",theVals,numElements);
  printToBaseMonitor("Battery",theVals,numElements);
}
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

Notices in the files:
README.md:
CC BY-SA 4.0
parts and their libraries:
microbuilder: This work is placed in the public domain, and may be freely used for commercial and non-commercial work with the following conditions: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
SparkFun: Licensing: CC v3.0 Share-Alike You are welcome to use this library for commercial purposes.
